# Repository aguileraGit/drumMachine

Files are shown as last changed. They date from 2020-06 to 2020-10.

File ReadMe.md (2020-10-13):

- Downloaded SVG: https://www.flaticon.com/free-icon/drum-set_1776571
- Used Inkspace to slice and dice into layers (See folder)
- Convert SVG layers into Eagle scr. (See folder) https://gfwilliams.github.io/svgtoeagle/
 - Mask: Take part to mask. Add 10px stroke. Select Path. Path-Outset
- Merge into ItsyBitsy-M0: https://github.com/adafruit/Adafruit-ItsyBitsy-M0-PCB
- LEDs: https://www.digikey.com/products/en?mpart=3341&v=1528
- https://learn.adafruit.com/introducing-itsy-bitsy-m0/pinouts
- Touch Pins: The following pins have hardware capacitive touch capability: A0, A1, A2, A3, A4, A5, and D9

- ~~Need to add D13 back in!~~
- ~~Is AREF needed?~~ Deleted
- ~~Need to reverse component side~~ None to be found
- ~~SWDIO and SWCLK header - 4 pin square~~

207 - Title - Silkscreen
206 - Bass Drum - Top Copper
205 - Top Drums - Top Copper & Soldermask
204 - Drums & Cymbals - Top Copper
203 - Silkscreen

Waterproof USB Micro: https://www.digikey.com/short/zphm51

Reset pull-up?

Memory:
- https://www.digikey.com/short/zp9vq1

USB:
- Adafruit: https://www.adafruit.com/product/4023
- A108263CT-ND
- 3D Model: https://www.te.com/usa-en/product-2040002-1.html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

LED:
- https://www.digikey.com/short/zphmfp

uC:
- https://www.digikey.com/short/zphmwt

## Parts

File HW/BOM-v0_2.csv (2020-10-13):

Qty | Value | Device | Package | Parts | Description | ARROW_ELECTRONICS-PURCHASE-URL | BOM | COMMENT | DESCRIPTION | DIGI-KEY_PART_NUMBER | DIGIKEY-PURCHASE-URL | DK_PN | JLC_PN | MF | MOUSER-PURCHASE-URL | MP | PACKAGE | PN | POPULARITY | TP_SIGNAL_NAME
1 |  | PINHD-2X2 | 2X02 | JP2 | PIN HEADER |  |  |  |  |  |  |  |  |  |  |  |  |  | 0
7 | 0 | RESISTOR_0603_NOOUT | 0603-NO | R3, R4, R5, R6, R8, R9, R10 | Resistors |  |  |  |  |  |  | P0.0GCT-ND | 0
1 | 1-2295018-2 | 1-2295018-2 | TE_1-2295018-2 | J2 | SPLASH PROOF USB TYPE C REC, DUAL SMT; Tape/Reel of 900 | https://snapeda.com/shop?store=Arrow+Electronics&id=2782217 |  | 1-2295018-2 | USB TYPE C, REC OFFSET 0.65MM DUAL SMT | A124378CT-ND | https://snapeda.com/shop?store=DigiKey&id=2782217 |  |  | TE Connectivity | https://snapeda.com/shop?store=Mouser&id=2782217 | 1-2295018-2 | None
2 | 100k | RESISTOR_0603_NOOUT | 0603-NO | R1, R2 | Resistors |  |  |  |  |  |  | P100KDBCT-ND | 100k
2 | 10µF | CAP_CERAMIC0805-NOOUTLINE | 0805-NO | C6, C8 | Ceramic Capacitors |  |  |  |  |  |  | 490-14381-1-ND | 10uF
3 | 1uF | CAP_CERAMIC0603_NO | 0603-NO | C1, C5, C7 | Ceramic Capacitors |  |  |  |  |  |  | 399-17705-1-ND | 1uF
1 | 2.2K | RESISTOR_0603_NOOUT | 0603-NO | R7 | Resistors |  |  |  |  |  |  | P2.2KDBCT-ND | 2.2k
7 | AP102-2020 | APA1022020 | APA102_2020 | L1, L2, L3, L4, L5, L6, L7 | APA102/DotStar Pixels |  |  |  |  |  |  | 1528-1826-ND |  |  |  |  |  | 3341
1 | AP2112K-3.3 | VREG_SOT23-5 | SOT23-5 | U2 | SOT23-5 Fixed Voltage Regulators |  |  |  |  |  |  | AP2112K-3.3TRG1DICT-ND | AP2112K-3.3TRG1 |  |  |  |  | AP2112K-3.3TRG1
1 | ATSAMD21G18 | ATSAMD21G_QFN | TQFN48_7MM | U$4 |  |  |  |  |  |  |  | ATSAMD21G18A-MU-ND |  |  |  |  |  | ATSAMD21G18A-MU
2 | FIDUCIAL_1MM | FIDUCIAL_1MM | FIDUCIAL_1MM | U$34, U$35 | Fiducial Alignment Points |  | EXCLUDE
1 | MBR120 | DIODE_SOD-123FL | SOD-123FL | D2 | Diode |  |  |  |  |  |  | MBR120LSFT1GOSCT-ND | MBR120LSF
1 | RED | LED0805_NOOUTLINE | CHIPLED_0805_NOOUTLINE | L | LED |  |  |  |  |  |  | 475-1415-1-ND | RED LED
1 | SPST_TACT-KMR2 | SPST_TACT-KMR2 | KMR2 | SW1 | SMT 6mm switch, EVQQ2 series |  |  |  |  |  |  | 401-1426-1-ND |  |  |  |  |  | KMR211GLFS
4 | TPB1,27 | TPB1,27 | B1,27 | TP1, TP2, TP3, TP4 | Test pad |  |  |  |  |  |  |  |  |  |  |  |  |  | 19
1 | flash | SPIFLASH_8PINUX | USON8 | U1 | SOIC8 SPI Flash |  |  |  |  |  |  | 1970-1011-1-ND |  |  |  |  |  | GD25Q16CEIGR

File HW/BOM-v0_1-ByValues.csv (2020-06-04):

Qty | Value | Device | Package | Parts | Description | AVAILABILITY | BOM | CENTERLINE_PITCH | COMMENT | DESCRIPTION | DK_PN | JLC_PN | MF | MP | NUMBER_OF_POSITIONS | PACKAGE | PN | POPULARITY | PRICE | PRODUCT_TYPE | TE_PURCHASE_URL
1 |  | PINHD-2X2 | 2X02 | JP2 | PIN HEADER |  |  |  |  |  |  |  |  |  |  |  |  | 0
7 | 0 | RESISTOR_0603_NOOUT | 0603-NO | R3, R4, R5, R6, R8, R9, R10 | Resistors |  |  |  |  |  | P0.0GCT-ND | 0
2 | 100k | RESISTOR_0603_NOOUT | 0603-NO | R1, R2 | Resistors |  |  |  |  |  | P100KDBCT-ND | 100k
2 | 10µF | CAP_CERAMIC0805-NOOUTLINE | 0805-NO | C6, C8 | Ceramic Capacitors |  |  |  |  |  | 490-14381-1-ND | 10uF
3 | 1uF | CAP_CERAMIC0603_NO | 0603-NO | C1, C5, C7 | Ceramic Capacitors |  |  |  |  |  | 399-17705-1-ND | 1uF
7 | 1uF | CAP_CERAMIC0603_NO | 0603-NO | C2, C3, C4, C9, C10, C11, C12 | Ceramic Capacitors
1 | 2.2K | RESISTOR_0603_NOOUT | 0603-NO | R7 | Resistors |  |  |  |  |  | P2.2KDBCT-ND | 2.2k
1 | 2040002-1 | 2040002-1 | TE_2040002-1 | J1 | Conn USB Type B RCP 5 POS 0.65mm Solder RA SMD 5 Terminal 1 Port T/R | Unavailable |  | .65 mm[.025 in] | 2040002-1 | Conn Micro USB 2.0 Type B RCP 5 POS 0.65mm Solder RA SMD 5 Terminal 1 Port T/R | A108263CT-ND |  | TE Connectivity | 2040002-1 | 5 | None | 2040002-1 |  | None | Connector | https://www.te.com/usa-en/product-2040002-1.html?te_bu=Cor&te_type=disp&elqCampaignId=32493
7 | AP102-2020 | APA1022020 | APA102_2020 | L1, L2, L3, L4, L5, L6, L7 | APA102/DotStar Pixels |  |  |  |  |  | 1528-1826-ND |  |  |  |  |  | 3341
1 | AP2112K-3.3 | VREG_SOT23-5 | SOT23-5 | U2 | SOT23-5 Fixed Voltage Regulators |  |  |  |  |  | AP2112K-3.3TRG1DICT-ND | AP2112K-3.3TRG1 |  |  |  |  | AP2112K-3.3TRG1
1 | ATSAMD21G18 | ATSAMD21G_QFN | TQFN48_7MM | U$4 |  |  |  |  |  |  | ATSAMD21G18A-MU-ND |  |  |  |  |  | ATSAMD21G18A-MU
2 | FIDUCIAL_1MM | FIDUCIAL_1MM | FIDUCIAL_1MM | U$34, U$35 | Fiducial Alignment Points |  | EXCLUDE
1 | MBR120 | DIODE_SOD-123FL | SOD-123FL | D2 | Diode |  |  |  |  |  | MBR120LSFT1GOSCT-ND | MBR120LSF
1 | RED | LED0805_NOOUTLINE | CHIPLED_0805_NOOUTLINE | L | LED |  |  |  |  |  | 475-1415-1-ND | RED LED
1 | SPST_TACT-KMR2 | SPST_TACT-KMR2 | KMR2 | SW1 | SMT 6mm switch, EVQQ2 series |  |  |  |  |  | 401-1426-1-ND |  |  |  |  |  | KMR211GLFS
1 | flash | SPIFLASH_8PINUX | USON8 | U1 | SOIC8 SPI Flash |  |  |  |  |  | 1092-1184-1-ND |  |  |  |  |  | MX25R2035FZUIL0

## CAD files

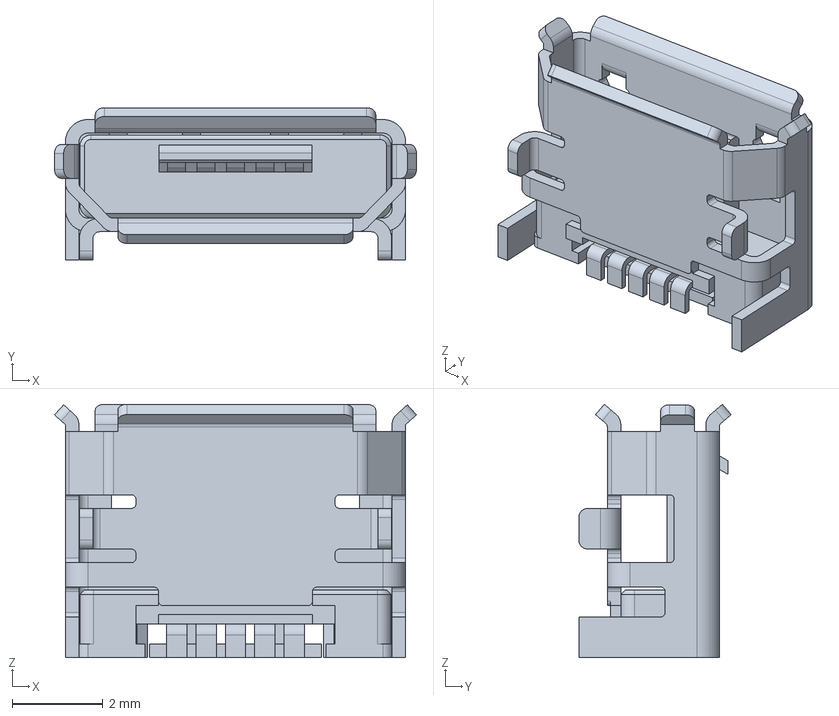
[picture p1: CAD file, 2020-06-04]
2040002-1/c-2040002-1-d-3d.stp
8.00 x 3.37 x 5.60 mm

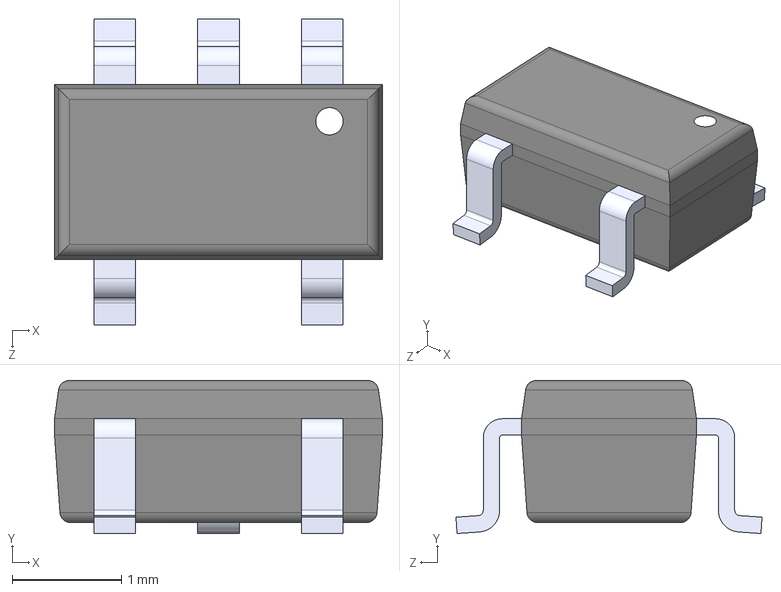
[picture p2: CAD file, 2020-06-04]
AP2112K-3.3TRG1--3DModel-STEP-56544.STEP
3.00 x 1.40 x 2.80 mm

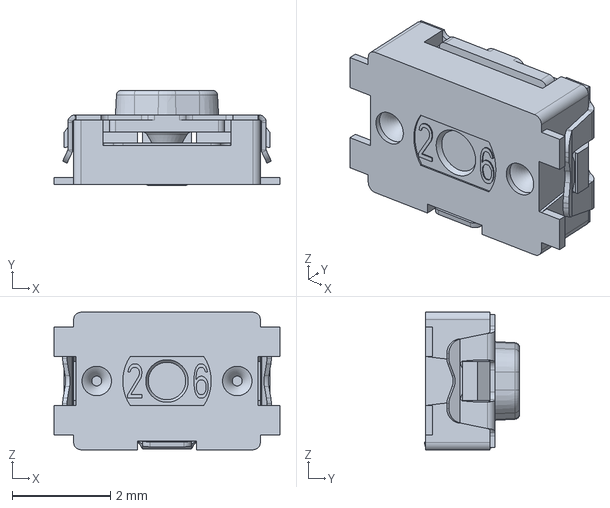
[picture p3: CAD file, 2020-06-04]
CKCOMPONENTS_KMR211GLFS/KMR211GLFS.stp
4.60 x 1.94 x 2.80 mm

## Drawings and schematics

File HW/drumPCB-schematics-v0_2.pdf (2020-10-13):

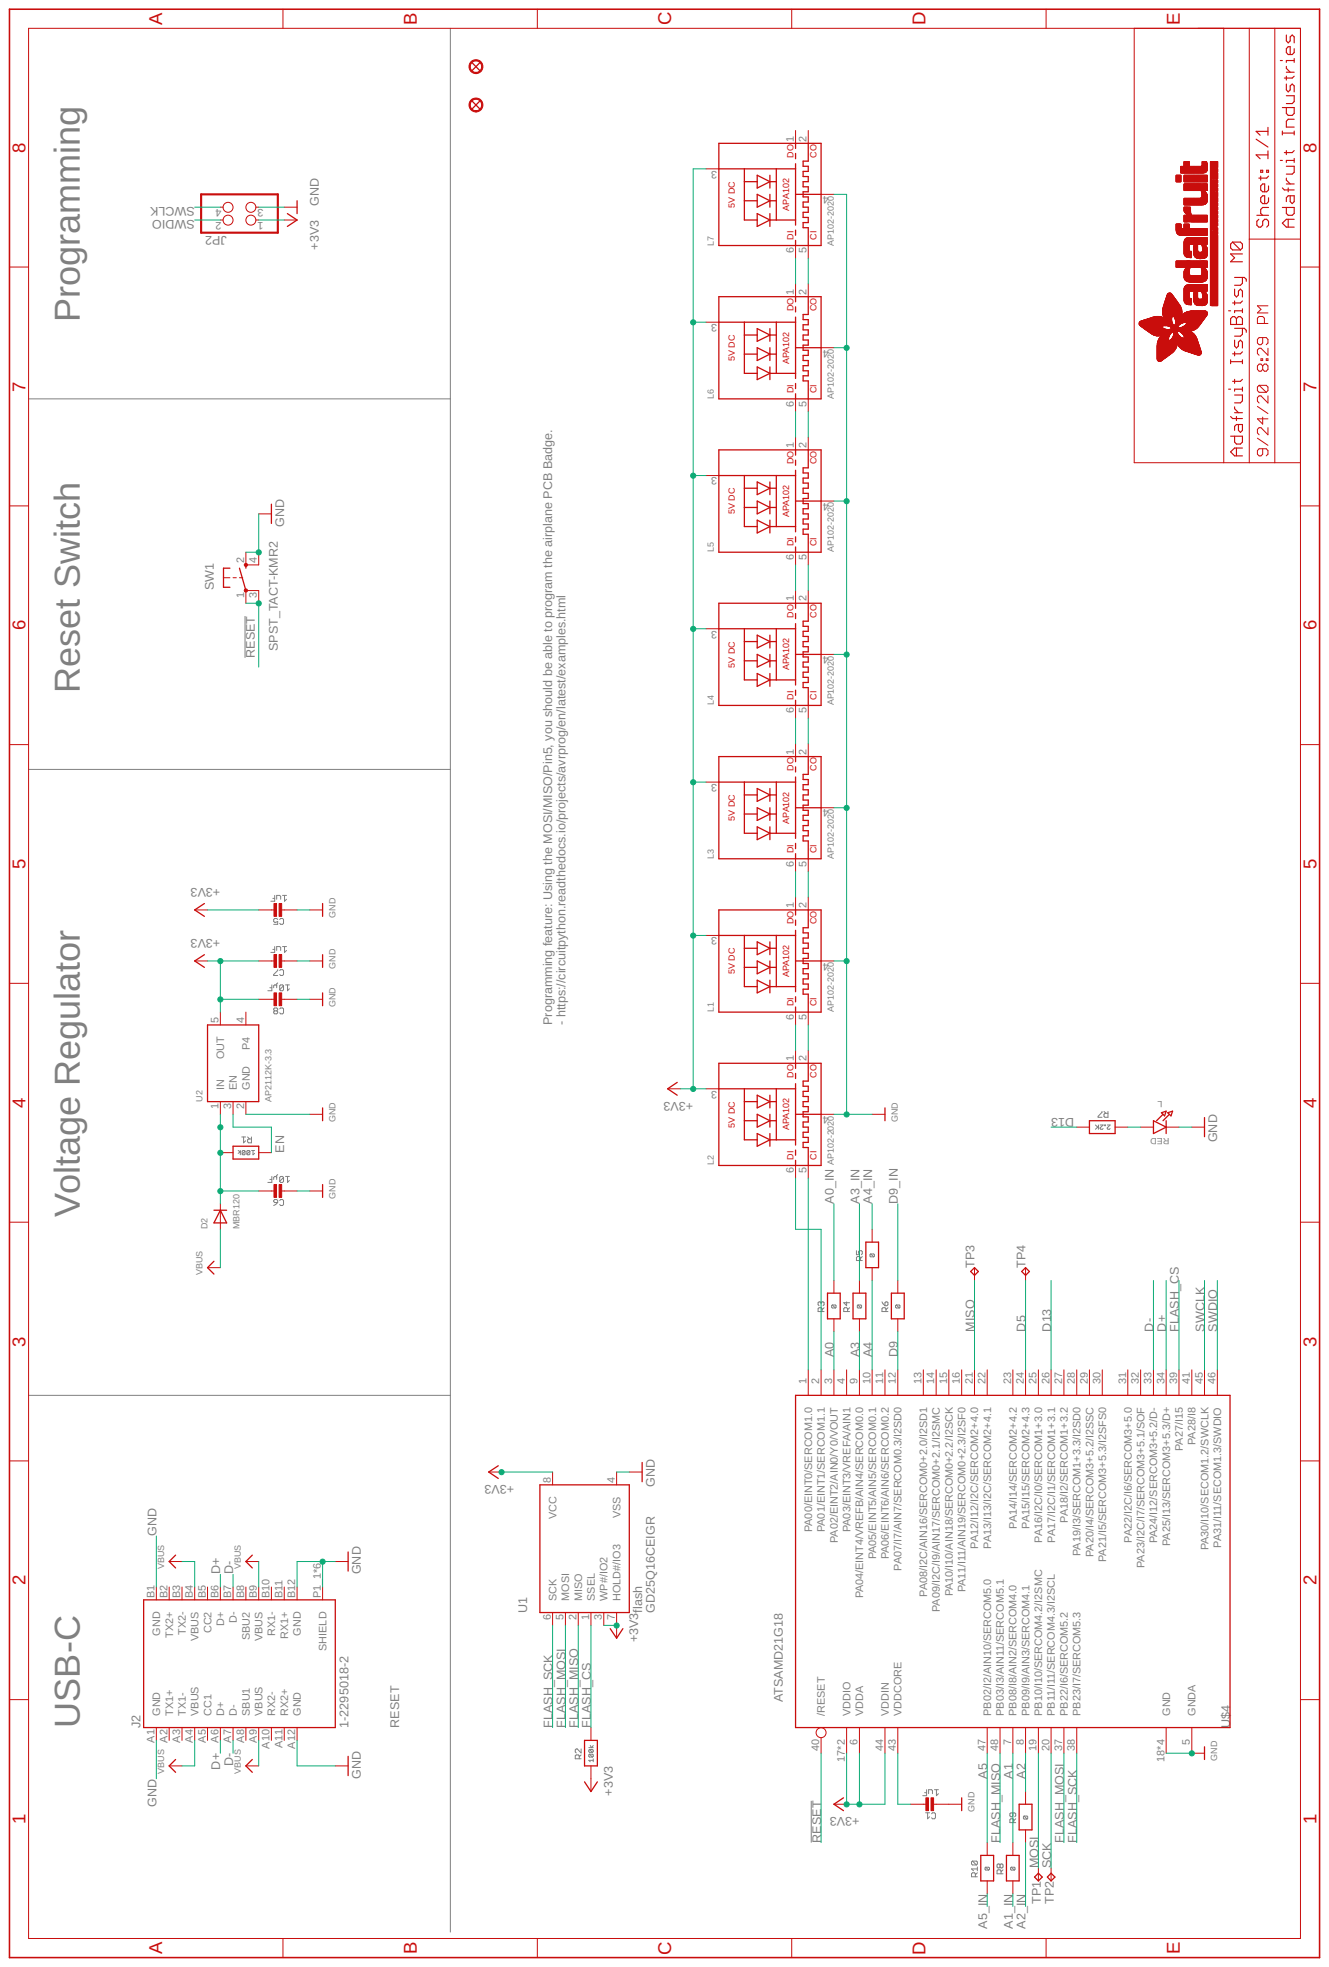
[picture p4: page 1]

RESET GD25Q16CEIGR USB-C Voltage Regulator Reset Switch Programming Programming feature: Using the MOSI/MISO/Pin5, you should be able to program the airplane PCB Badge. - https:/ circuitpython.readthedocs.io/projects/avrprog/en/latest/examples.html GND GND GND GND DER GND GND SPST_TACT-KMR2 3V3+ VBUS ATSAMD21G18 GND 3V3+ GND 3V3+ GND MBR120 AP102-2020 3V3+ GND GND +3V3 3V3+ +3V3 AP102-2020 AP102-2020 AP102-2020 AP102-2020 AP102-2020 AP102-2020GND +3V3 1-2295018-2 VBUS VBUS VBUS VBUS GND GND L 1 24 3SW1 IN 1 OUT 5 EN 3 GND 2 P4 4 U2 AP2112K-3.3 GND 18*4 VDDA 6 PA16/I2C/I0/SERCOM1+3.0 25 PA17/I2C/I1/SERCOM1+3.1 26 PA18/I2/SERCOM1+3.2 27 PA19/I3/SERCOM1+3.3/I2SD0 28 PA22/I2C/I6/SERCOM3+5.0 31 PA23/I2C/I7/SERCOM3+5.1/SOF 32 PA24/I12/SERCOM3+5.2/D- 33 PA25/I13/SERCOM3+5.3/D+ 34 PA27/I15 39 PA28/I8 41 PA30/I10/SECOM1.2/SWCLK 45 PA31/I11/SECOM1.3/SWDIO 46 PA09/I2C/I9/AIN17/SERCOM0+2.1/I2SMC 14 PA08/I2C/AIN16/SERCOM0+2.0/I2SD1 13 PA15/I15/SERCOM2+4.3 24 PA11/I11/AIN19/SERCOM0+2.3/I2SF0 16 PA14/I14/SERCOM2+4.2 23 PA10/I10/AIN18/SERCOM0+2.2/I2SCK 15 /RESET 40 PA06/EINT6/AIN6/SERCOM0.2 11 PA00/EINT0/SERCOM1.0 1 PA01/EINT1/SERCOM1.1 2 PA02/EINT2/AIN0/Y0/VOUT 3 PA03/EINT3/VREFA/AIN1 4 PA04/EINT4/VREFB/AIN4/SERCOM0.0 9 PA05/EINT5/AIN5/SERCOM0.1 10 PA07/I7/AIN7/SERCOM0.3/I2SD0 12 VDDIN 44 GNDA 5 VDDIO 17*2 VDDCORE 43 PB08/I8/AIN2/SERCOM4.0 7 PB09/I9/AIN3/SERCOM4.1 8 PB10/I10/SERCOM4.2/I2SMC 19 PB11/I11/SERCOM4.3/I2SCL 20 PA12/I12/I2C/SERCOM2+4.0 21 PA13/I13/I2C/SERCOM2+4.1 22 PA20/I4/SERCOM3+5.2/I2SSC 29 PA21/I5/SERCOM3+5.3/I2SFS0 30 PB22/I6/SERCOM5.2 37 PB23/I7/SERCOM5.3 38 PB02/I2/AIN10/SERCOM5.0 47 PB03/I3/AIN11/SERCOM5.1 48 U$4 D2 3 6 4 1 5 2 L2 SCK 6 MOSI 5 MISO 2 SSEL 1 WP#/IO2 3 HOLD#/IO3 7 VCC 8 VSS 4 U1 flash 3 6 4 1 5 2 L1 3 6 4 1 5 2 L3 3 6 4 1 5 2 L4 3 6 4 1 5 2 L5 3 6 4 1 5 2 L6 3 6 4 1 5 2 L7 2 1 4 3 2PJ GND A1 TX1+ A2 TX1- A3 VBUS A4 CC1 A5 D+ A6 D- A7 SBU1 A8 VBUS A9 RX2- A10 RX2+ A11 GND A12 GND B1 TX2+ B2 TX2- B3 VBUS B4 CC2 B5 D+ B6 D- B7 SBU2 B8 VBUS B9 RX1- B10 RX1+ B11 GND B12 SHIELD P1_1*6 J2 TP1 TP2 TP3 TP4 GND GND A5 A4A3 A2A1 31 D D13 A0D9 D+ D+ D+ D- D- D- RESET RESET SWCLK KL C WS SWDIO OI D WS EN FLASH_SCK FLASH_SCK FLASH_MOSI FLASH_MOSI FLASH_MISO FLASH_MISO FLASH_CS FLASH_CS A0_IN A3_IN A4_IN D9_IN A1_IN A2_IN A5_IN MOSI SCK MISO D5 APA102 DI DO CI CO 5V DC ABCDE 1 2 3 4 5 6 7 8 ABCDE 1 2 3 4 5 6 7 8 APA102 DI DO CI CO 5V DC APA102 DI DO CI CO 5V DC APA102 DI DO CI CO 5V DC APA102 DI DO CI CO 5V DC APA102 DI DO CI CO 5V DC APA102 DI DO CI CO 5V DC

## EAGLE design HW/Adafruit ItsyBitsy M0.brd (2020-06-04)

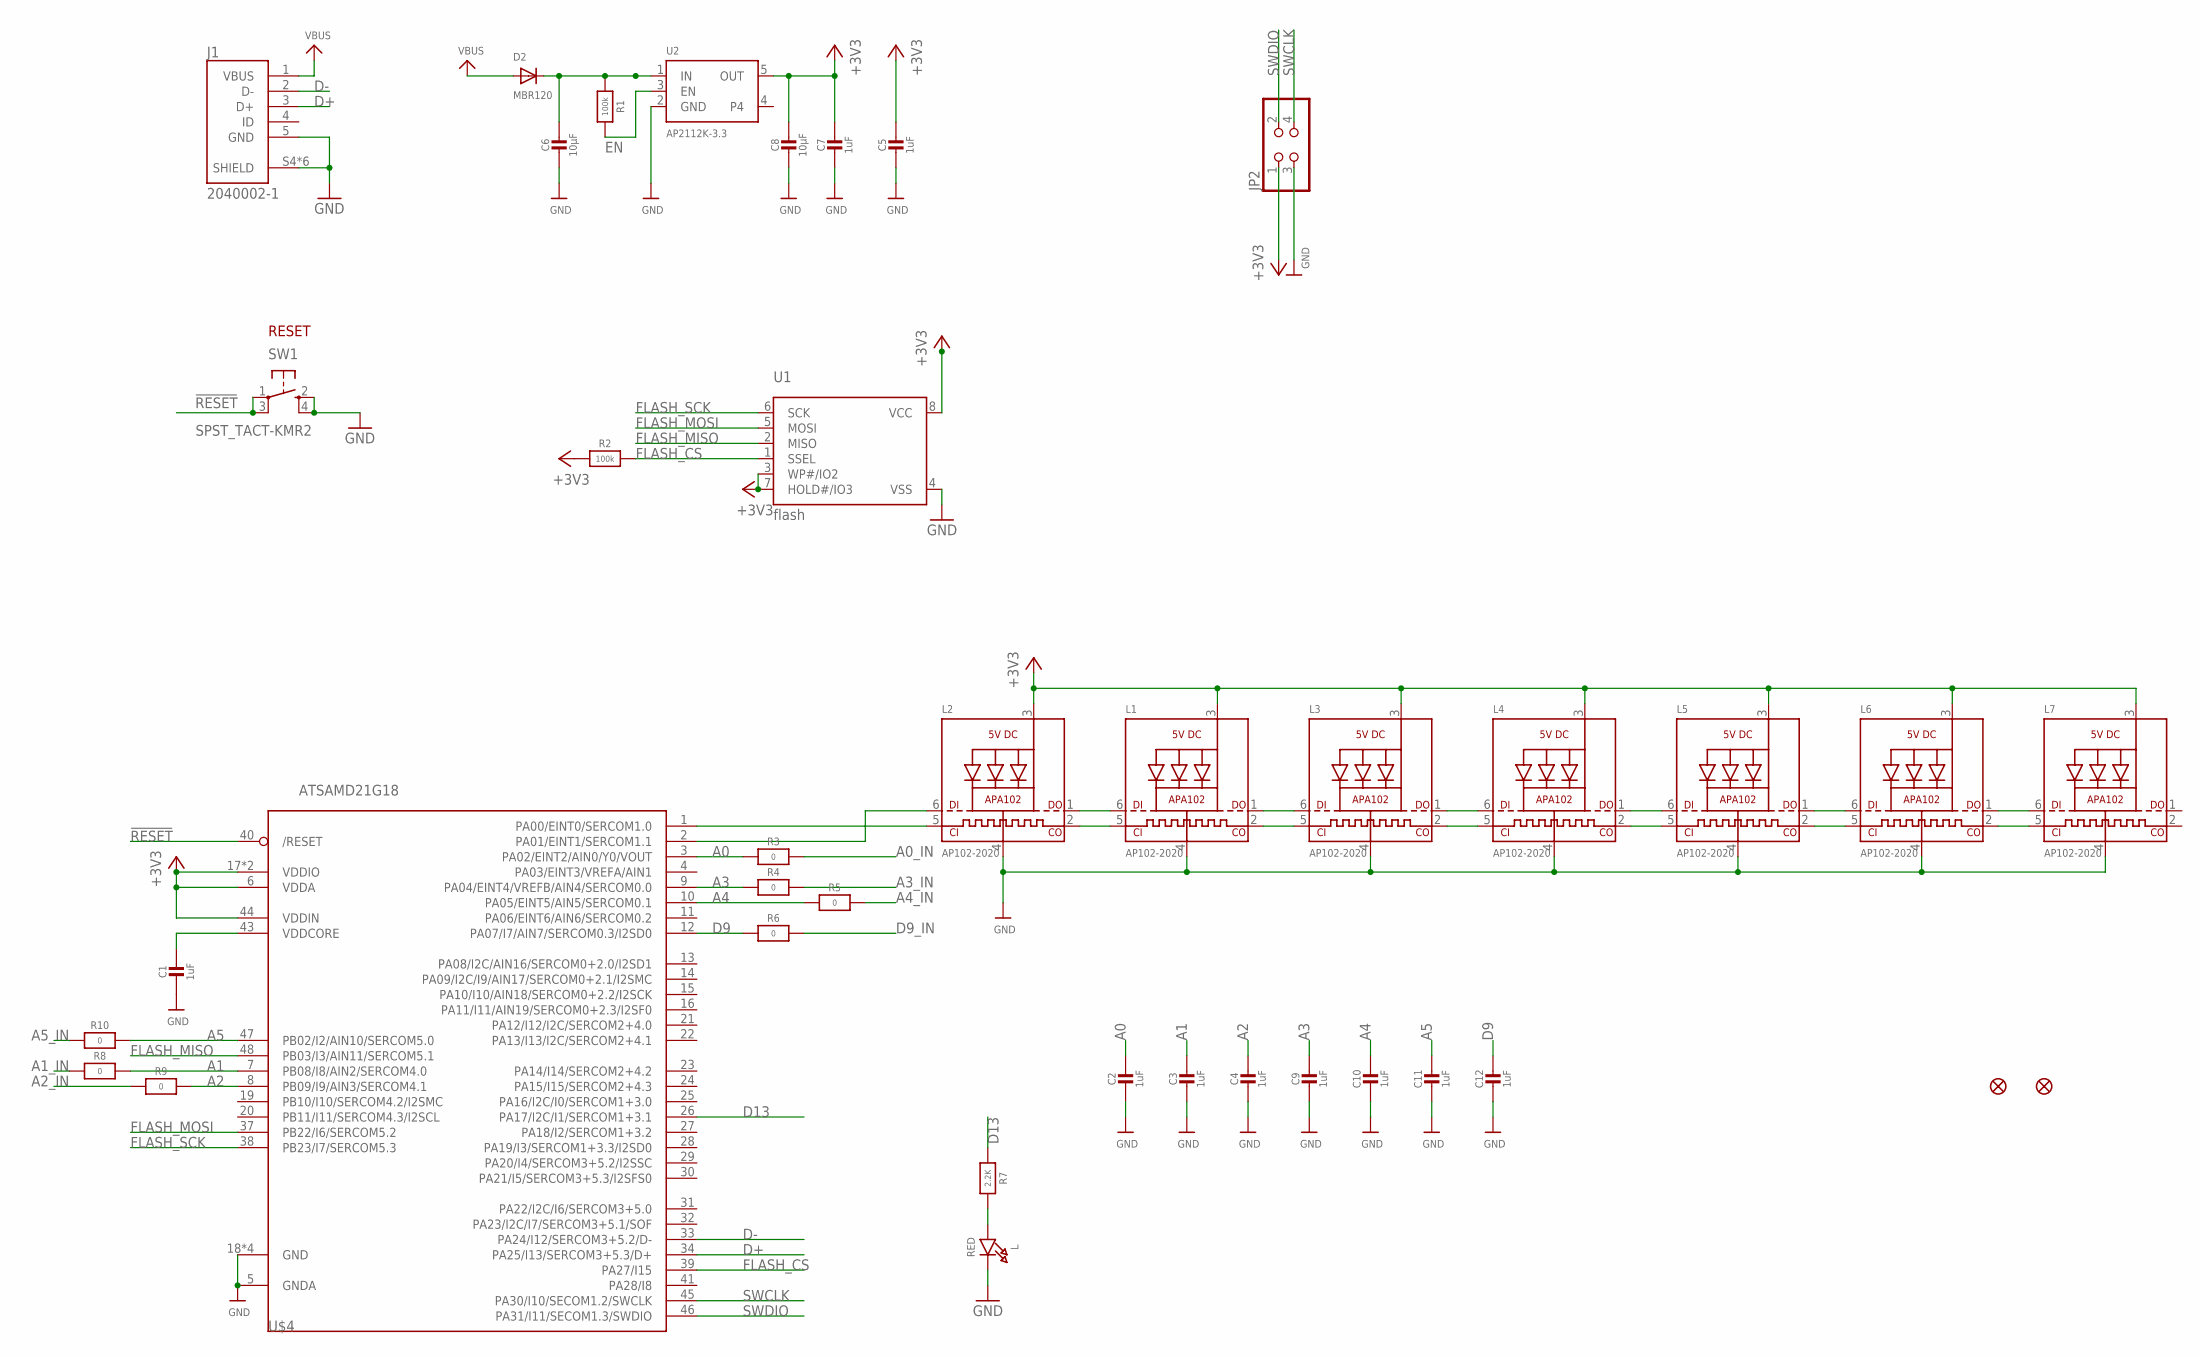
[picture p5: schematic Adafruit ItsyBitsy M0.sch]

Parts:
C1, C5, C7: 1uF; 0603-NO; JLC_PN 1uF
C2, C3, C4, C9, C10, C11, C12: 1uF; 0603-NO
C6, C8: 10µF; 0805-NO; JLC_PN 10uF
D2: MBR120; SOD-123FL; JLC_PN MBR120LSF
J1: 2040002-1; TE_2040002-1
JP2: PINHD-2X2; 2X02
L: RED; CHIPLED_0805_NOOUTLINE; JLC_PN RED LED
L1, L2, L3, L4, L5, L6, L7: AP102-2020; APA102_2020
R1, R2: 100k; 0603-NO; JLC_PN 100k
R3, R4, R5, R6, R8, R9, R10: 0; 0603-NO; JLC_PN 0
R7: 2.2K; 0603-NO; JLC_PN 2.2k
SW1: SPST_TACT-KMR2; KMR2
U1: flash; USON8
U2: AP2112K-3.3; SOT23-5; JLC_PN AP2112K-3.3TRG1
U$4: ATSAMD21G18; TQFN48_7MM
U$34, U$35: FIDUCIAL_1MM

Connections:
!RESET: SW1.1, SW1.3 (P1), U$4.40 (/RESET)
+3V3: C5.1, C7.1, C8.1, JP2.1, L1.3 (VDD), L2.3 (VDD), L3.3 (VDD), L4.3 (VDD), L5.3 (VDD), L6.3 (VDD), L7.3 (VDD), R2.1, U1.3 (WP#/IO2), U1.7 (HOLD#/IO3), U1.8 (VCC), U2.5 (OUT), U$4.6 (VDDA), U$4.17 (VDDIO), U$4.36 (VDDIO), U$4.44 (VDDIN)
A0: C2.1, R3.1, U$4.3 (PA02/EINT2/AIN0/Y0/VOUT)
A0_IN: R3.2
A1: C3.1, R8.2, U$4.7 (PB08/I8/AIN2/SERCOM4.0)
A1_IN: R8.1
A2: C4.1, R9.2, U$4.8 (PB09/I9/AIN3/SERCOM4.1)
A2_IN: R9.1
A3: C9.1, R4.1, U$4.9 (PA04/EINT4/VREFB/AIN4/SERCOM0.0)
A3_IN: R4.2
A4: C10.1, R5.1, U$4.10 (PA05/EINT5/AIN5/SERCOM0.1)
A4_IN: R5.2
A5: C11.1, R10.2, U$4.47 (PB02/I2/AIN10/SERCOM5.0)
A5_IN: R10.1
D9: C12.1, R6.1, U$4.12 (PA07/I7/AIN7/SERCOM0.3/I2SD0)
D9_IN: R6.2
D13: R7.1, U$4.26 (PA17/I2C/I1/SERCOM1+3.1)
D+: J1.3 (D+), U$4.34 (PA25/I13/SERCOM3+5.3/D+)
D-: J1.2 (D-), U$4.33 (PA24/I12/SERCOM3+5.2/D-)
EN: R1.2, U2.3 (EN)
FLASH_CS: R2.2, U1.1 (SSEL), U$4.39 (PA27/I15)
FLASH_MISO: U1.2 (MISO), U$4.48 (PB03/I3/AIN11/SERCOM5.1)
FLASH_MOSI: U1.5 (MOSI), U$4.37 (PB22/I6/SERCOM5.2)
FLASH_SCK: U1.6 (SCK), U$4.38 (PB23/I7/SERCOM5.3)
GND: C1.2, C2.2, C3.2, C4.2, C5.2, C6.2, C7.2, C8.2, C9.2, C10.2, C11.2, C12.2, J1.5 (GND), J1.S4 (SHIELD), J1.S5 (SHIELD), J1.SH1 (SHIELD), J1.SH2 (SHIELD), J1.SH3 (SHIELD), J1.SH4 (SHIELD), JP2.3, L.C, L1.4 (GND), L2.4 (GND), L3.4 (GND), L4.4 (GND), L5.4 (GND), L6.4 (GND), L7.4 (GND), SW1.2 (S), SW1.4 (S1), U1.4 (VSS), U2.2 (GND), U$4.5 (GNDA), U$4.18 (GND), U$4.35 (GND), U$4.42 (GND), U$4.THERMAL (GND)
unnamed: L2.5 (CKI), U$4.1 (PA00/EINT0/SERCOM1.0)
unnamed: L.A, R7.2
unnamed: L1.6 (DI), L2.1 (DO)
unnamed: L1.5 (CKI), L2.2 (CKO)
unnamed: L2.6 (DI), U$4.2 (PA01/EINT1/SERCOM1.1)
unnamed: L1.1 (DO), L3.6 (DI)
unnamed: L1.2 (CKO), L3.5 (CKI)
unnamed: L3.1 (DO), L4.6 (DI)
unnamed: L3.2 (CKO), L4.5 (CKI)
unnamed: L4.1 (DO), L5.6 (DI)
unnamed: L4.2 (CKO), L5.5 (CKI)
unnamed: L5.1 (DO), L6.6 (DI)
unnamed: L5.2 (CKO), L6.5 (CKI)
unnamed: L6.1 (DO), L7.6 (DI)
unnamed: L6.2 (CKO), L7.5 (CKI)
SWCLK: JP2.4, U$4.45 (PA30/I10/SECOM1.2/SWCLK)
SWDIO: JP2.2, U$4.46 (PA31/I11/SECOM1.3/SWDIO)
VBUS: D2.A, J1.1 (VBUS)
VDDCORE: C1.1, U$4.43 (VDDCORE)
VHI: C6.1, D2.C, R1.1, U2.1 (IN)

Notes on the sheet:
RESET

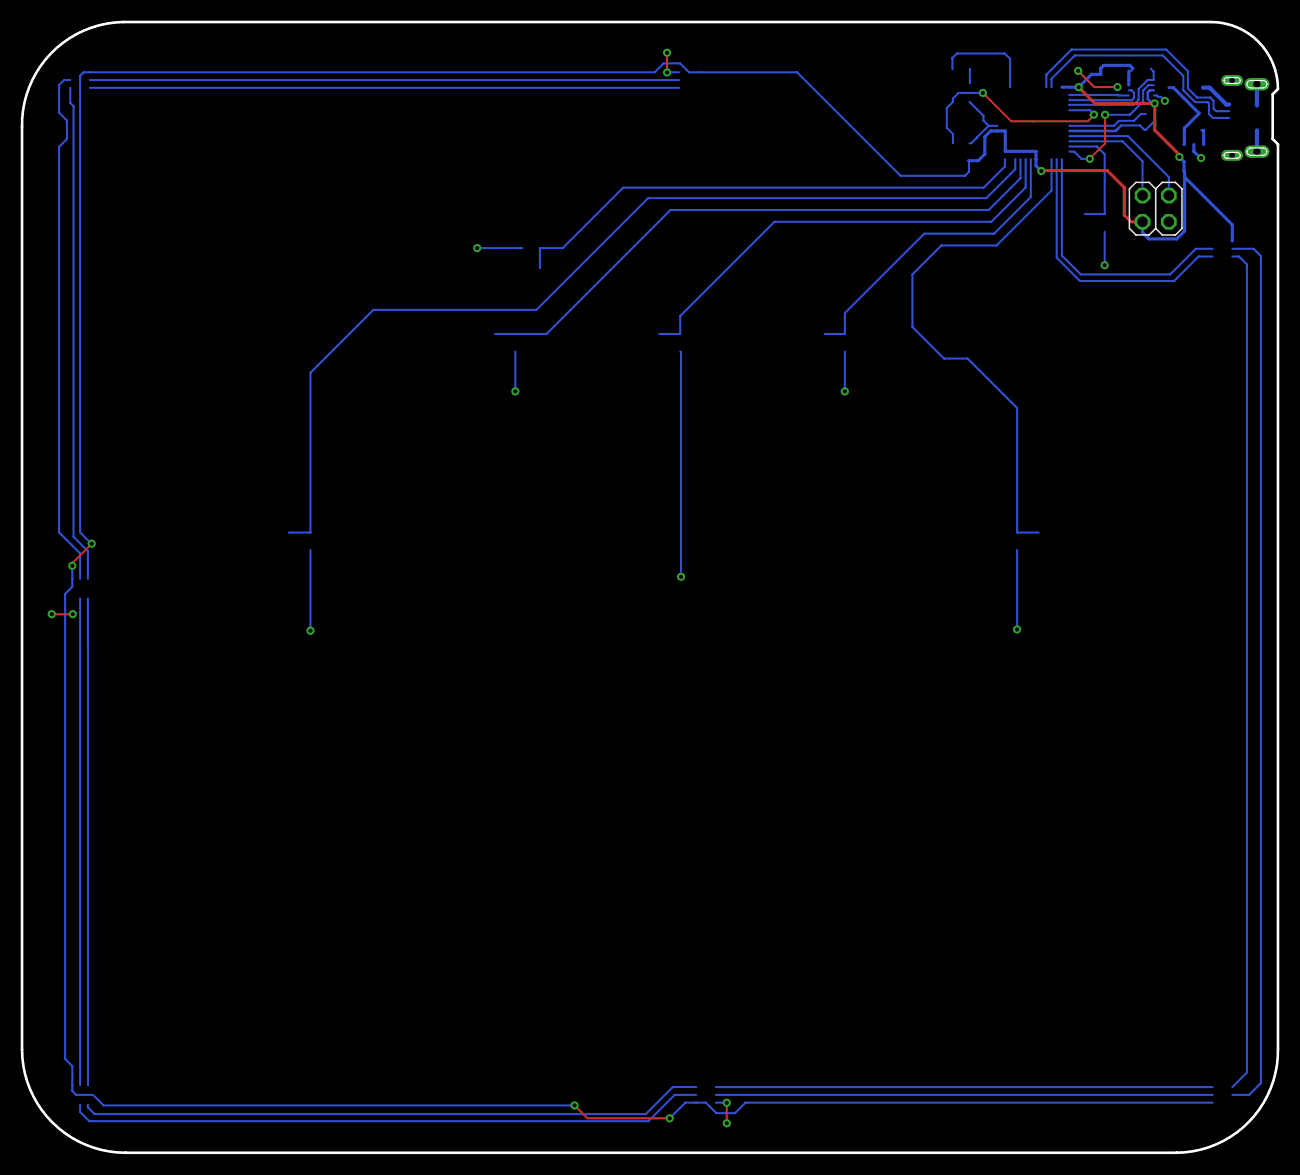
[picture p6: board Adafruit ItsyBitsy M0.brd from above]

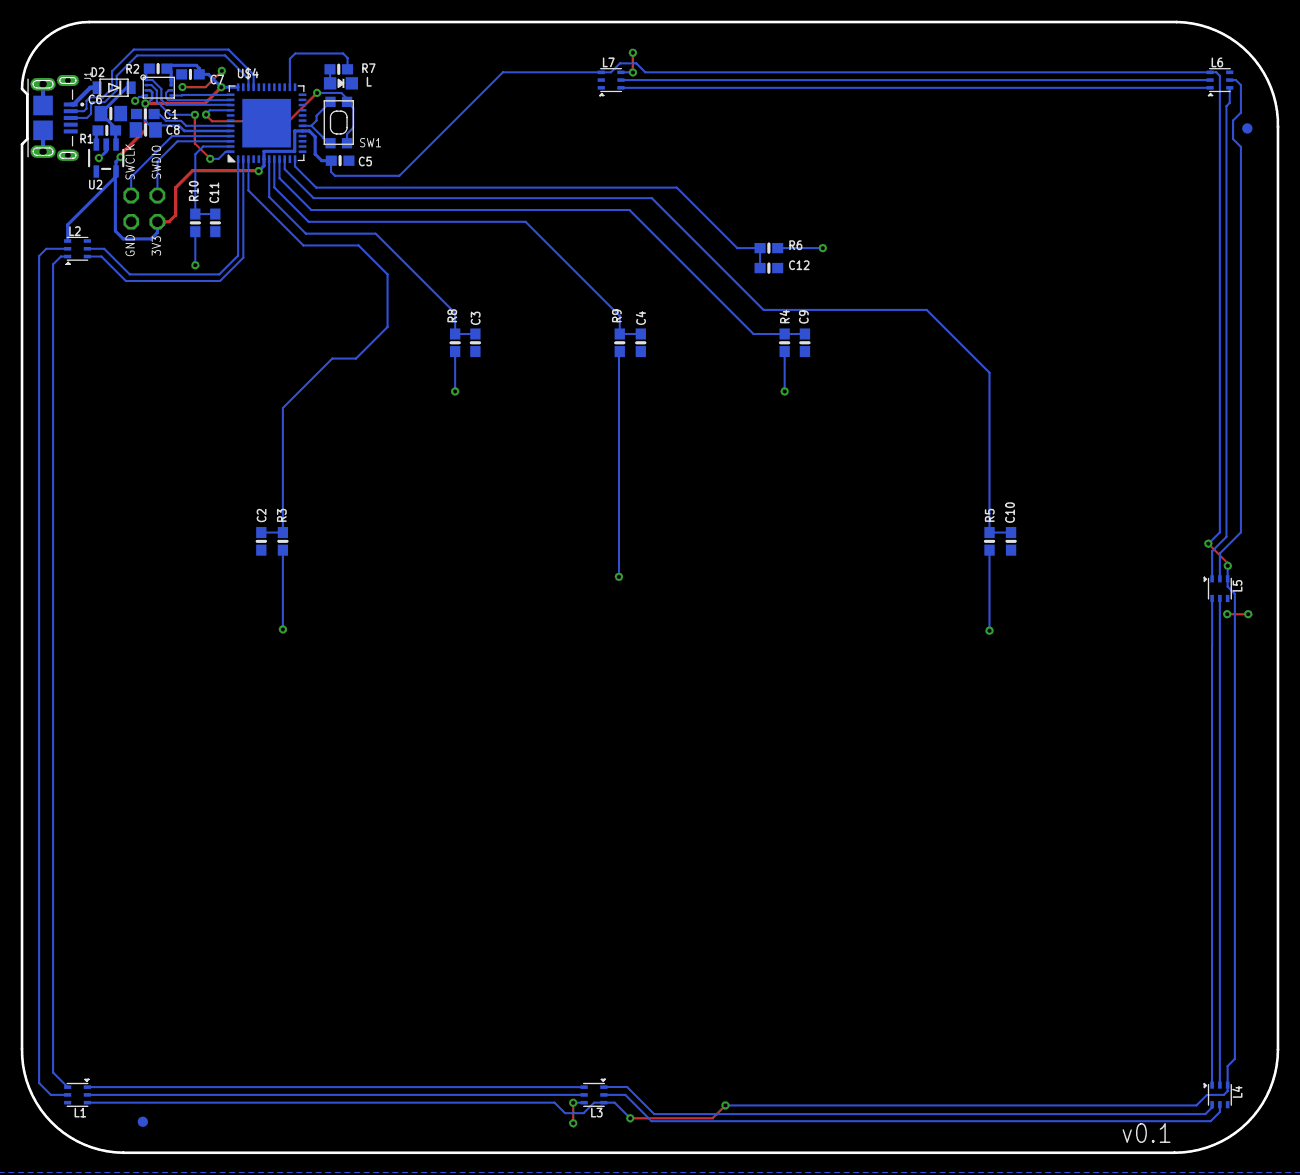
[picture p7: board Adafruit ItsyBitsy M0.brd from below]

Board: 2 copper layers, 121.3 x 109.2 mm, 41 parts (39 on the bottom side), 38 nets.

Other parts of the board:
U$14: ITSYM0_TOP
U$15: ITSYM0_BOT

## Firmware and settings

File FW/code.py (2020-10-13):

#https://learn.adafruit.com/circuitpython-essentials/circuitpython-cap-touch
#https://www.silabs.com/documents/public/application-notes/AN0040.pdf
#https://music.stackexchange.com/questions/7227/what-keys-are-associated-to-what-drums-when-connecting-keyboard-to-roland-electr

import board
import digitalio
import touchio
import time
import usb_midi
import adafruit_midi
from adafruit_midi.note_on import NoteOn
from adafruit_midi.note_off import NoteOff
import adafruit_dotstar

#Debug the touch pads
debugCode = False

#Default time to wait after a drum is hit
defaultSleepTime = 1

#DotStar define colors
RED = (255, 0, 0)
YELLOW = (255, 150, 0)
ORANGE = (255, 40, 0)
GREEN = (0, 255, 0)
TEAL = (0, 255, 120)
CYAN = (0, 255, 255)
BLUE = (0, 0, 255)
PURPLE = (180, 0, 255)
MAGENTA = (255, 0, 20)
WHITE = (255, 255, 255)

#DotStar Fill
def color_fill(color, wait):
    dot.fill(color)
    dot.show()
    #time.sleep(wait)

class createDrum():
    def __init__(self, touchPin, note, velocity, waitTime, midi, led):

        #Need to add states - padTouched, sendingNote, setRunTime, disabled
        #pad is sending note while finger is still present

        self.touch = touchio.TouchIn(touchPin)
        self.note = note
        self.velocity = velocity
        self.waitTime = waitTime
        self.midi = midi
        self.led = led
        self.noteTimeoutValue = None
        self.running = False #Waits for timer to expire
        self.enabled = True #Enables pad completely.

    def sendNote(self):
        self.midi.send(NoteOn(self.note, self.velocity))

    def stopNote(self):
        self.midi.send(NoteOff(self.note, self.velocity))

    def ledEnable(self):
        self.led.value = True

    def ledDisable(self):
        self.led.value = False

    def setTimeout(self, timeValue):
        self.noteTimeoutValue = timeValue + self.waitTime
        self.running = True

    def queryTimeout(self):
        return self.noteTimeoutValue


#Setup LED
led = digitalio.DigitalInOut(board.D13)
led.direction = digitalio.Direction.OUTPUT

#Setup DotStar
num_pixels = 7
dot = adafruit_dotstar.DotStar(board.APA102_SCK, board.APA102_MOSI, num_pixels, brightness=0.5)

#Setup Midi
midi = adafruit_midi.MIDI(midi_out=usb_midi.ports[1], out_channel=0)

#Setup drums - touchPin, note, velocity, waitTime, midi, led
snare = createDrum(board.A0,       38, 120, defaultSleepTime, midi, led) #38
tom0 = createDrum(board.A1,        48, 120, defaultSleepTime, midi, led) #48
tom1 = createDrum(board.A3,        47, 120, defaultSleepTime, midi, led) #47
bass = createDrum(board.A2,        36, 120, defaultSleepTime, midi, led) #36
floorTom = createDrum(board.A4,    41, 120, defaultSleepTime, midi, led) #41
crashCymbal = createDrum(board.A5, 57, 120, defaultSleepTime, midi, led)
highHat = createDrum(board.D9,     42, 120, defaultSleepTime, midi, led)

while True:

    if debugCode:
        print('Snare - {}'.format(snare.touch.raw_value))
        print('tom0 - {}'.format(tom0.touch.raw_value))
        print('tom1 - {}'.format(tom1.touch.raw_value))
        print('floorTom - {}'.format(floorTom.touch.raw_value))
        print('crashCymbal - {}'.format(crashCymbal.touch.raw_value))
        print('highHat - {}'.format(highHat.touch.raw_value))
        print('bass - {}'.format(bass.touch.raw_value))
        print('\n')

        time.sleep(0.1)


    #Get current time
    currentTime = time.monotonic()


    if snare.enabled and snare.touch.raw_value < 4060: #<4062
        snare.enabled = False
        print('Snare')
        snare.sendNote()
        snare.setTimeout( time.monotonic() )
        time.sleep(0.1)
        color_fill(RED, 0.5)
        snare.enabled = True


    if tom0.enabled and tom0.touch.raw_value > 3800:
        tom0.enabled = False
        print('Tom 0')
        tom0.sendNote()
        tom0.setTimeout( time.monotonic() )
        time.sleep(0.1)
        color_fill(YELLOW, 0.5)
        tom0.enabled = True

    if tom1.enabled and tom1.touch.raw_value < 3800:
        tom1.enabled = False
        print('Tom 1')
        tom1.sendNote()
        tom1.setTimeout( time.monotonic() )
        time.sleep(0.1)
        color_fill(ORANGE, 0.5)
        tom1.enabled = True

    if floorTom.enabled and floorTom.touch.raw_value < 4000:
        floorTom.enabled = False
        print('Floor Tom')
        floorTom.sendNote()
        floorTom.setTimeout( time.monotonic() )
        time.sleep(0.1)
        color_fill(PURPLE, 0.5)
        floorTom.enabled = True

    if crashCymbal.enabled and crashCymbal.touch.raw_value > 1800:
        crashCymbal.enabled = False
        print('Crash Cymbal')
        crashCymbal.sendNote()
        crashCymbal.setTimeout( time.monotonic() )
        color_fill(BLUE, 0.5)
        time.sleep(0.1)
        crashCymbal.enabled = True

    if highHat.enabled and highHat.touch.value:
        highHat.enabled = False
        print('High Hat')
        highHat.sendNote()
        highHat.setTimeout( time.monotonic() )
        time.sleep(0.1)
        color_fill(GREEN, 0.5)
        highHat.enabled = True


    if bass.enabled and bass.touch.raw_value < 4000:
        bass.enabled = False
        print('Bass')
        bass.sendNote()
        bass.setTimeout( time.monotonic() )
        time.sleep(0.1)
        color_fill(TEAL, 0.5)
        bass.enabled = True


    #------------ Stop -------------#
    if snare.enabled and snare.running:
        #Time has expired
        if time.monotonic() > snare.queryTimeout():
            color_fill(WHITE, 0.5)
            snare.running = False
            snare.stopNote()

    if tom0.enabled and tom0.running:
        #Time has expired
        if time.monotonic() > tom0.queryTimeout():
            color_fill(WHITE, 0.5)
            tom0.running = False
            tom0.stopNote()

    if tom1.enabled and tom1.running:
        #Time has expired
        if time.monotonic() > tom1.queryTimeout():
            color_fill(WHITE, 0.5)
            tom1.running = False
            tom1.stopNote()

    if floorTom.enabled and floorTom.running:
        #Time has expired
        if time.monotonic() > floorTom.queryTimeout():
            color_fill(WHITE, 0.5)
            floorTom.running = False
            floorTom.stopNote()

    if crashCymbal.enabled and crashCymbal.running:
        #Time has expired
        if time.monotonic() > crashCymbal.queryTimeout():
            color_fill(WHITE, 0.5)
            crashCymbal.running = False
            crashCymbal.stopNote()

    if highHat.enabled and highHat.running:
        #Time has expired
        if time.monotonic() > highHat.queryTimeout():
            color_fill(WHITE, 0.5)
            highHat.running = False
            highHat.stopNote()

    if bass.enabled and bass.running:
        #Time has expired
        if time.monotonic() > bass.queryTimeout():
            color_fill(TEAL, 0.5)
            bass.running = False
            bass.stopNote()

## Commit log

2020-06-04 Init Commit
    [AP2112K-3.3TRG1--3DModel-STEP-56544.STEP, Adafruit ItsyBitsy M0.brd, Adafruit ItsyBitsy M0.sch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]
2020-10-13 Adding FW, CAM, and BOM
    [BOM-v0_2.csv, BOM-v0_2.xlsx]
2020-10-13 Adding PDF of schematics

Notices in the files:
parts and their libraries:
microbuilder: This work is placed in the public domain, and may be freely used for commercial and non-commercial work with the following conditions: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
